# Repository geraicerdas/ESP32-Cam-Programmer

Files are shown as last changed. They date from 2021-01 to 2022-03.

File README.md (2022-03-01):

### Repository Content
* **/hardware** : Schematic files (.pdf) some of older version included Eagle design files (.sch and .brd)
* **/production** : gerber file for pcb manufacturing

You can purchase this product from  


# ESP32-Cam-Programmer
This is external programming for ESP32-Cam that you can simple attach it for easy upload your code to ESP32-Cam. Keep the slide switch at 3.3V so it is not harmful for your ESP32-Cam. ESP32-Cam programmer also have a breakout pins that makes it easier for you to connect the I/O pins of the ESP32-Cam to other circuits (no need breadboard). Not only for ESP32-Cam, you can use this board to program another MCU's like Arduino Pro mini that need USB to Serial Converter

The latest version have several changes :
- Added a 3V3 Voltage Regulator
- Added voltage selector switch (5V or 3.3V compatible)
- Compatible with both older or newer ESP32-Cam
- changes PCB shape and color

<p float="left">
 

 
</p>

If you want to make your self, just download the gerber file in production folder. Send it to your fav pcb manufacturer. And dont forget to get the Bill of materials :
|Qty | Part Name | Parts | MPN |
| --- |:---|:---| -----:|
| 2 | Female Header 8P 2.54mm pitch | J5 | X6511FV-08-C85D32 |
| 2 | Male Header 8P 2.54mm pitch | J2, J3 | X4611WRS-08I-C40D28 |
| 1 | USB type C Connector 16P | J4 | U262-161N-4BVC11 |
| 1 | CH340G/CH340C | U1 | CH340G |
| 1 | SMD Resonator 12MHz CSTCE | X1 | CSTCE12M0G15C99-R0 |
| 1 | AP2112K-3.3TRG1 | U2 | AP2112K-3.3TRG1 |
| 1 | Chip Resistor 0 0805 | R10, R11 | 0805W8F0000T5E |
| 3 | Chip Resistor 1K 0603 | R4, R6, R7 | 0603WAF1001T5E |
| 3 | Chip Resistor 10K 0603 | R1, R2, R3 | 0603WAF1002T5E |
| 2 | Chip Resistor 4K7 0603 | R8, R9 | 0603WAF4701T5E |
| 5 | Chip Capacitor 100nF 0603 | C3, C5, C6, C8, C21 | CL10B104KB8NNNC |
| 3 | Chip Capacitor 10uF 0603 | C2, C4, C7 | CL10A106KP8NNNC |
| 1 | N-Channel MOSFET AO3400 | Q1 | AO3400 |
| 2 | Transistor S8050 | Q2, Q3 | S8050 |
| 2 | Slide Switch AYZ0202W | SW | SS-3390S-L2 |
| 2 | Push Button YD3414 | S1, S2 | TS-1186U-B-A |
| 2 | SMD LED 0805 Red | RX, TX | 17-21/R6C-AQ2R2B/3T |
| 1 | SMD LED 0805 Green | PWR | 17-21/GHC-YR1S2/3T |
| 1 | Schottky Diode 1N5819HW | D1 | 1N5819WS |

Below is the first version of ESP32-Cam Programmer. We keep this for your references.

<p float="left">
 
 

</p>

## License
*We invests time and resources providing this open-source hardware, please support us by purchasing our products.*

*Designed by **[Insan Sains](https://www.youtube.com/insansains)** for **[Gerai Cerdas](https://geraicerdas.com)**, with contributions from the open source community. Creative Commons Attribution/Share-Alike, all text above must be included in any redistribution. See license.txt for additional information.*

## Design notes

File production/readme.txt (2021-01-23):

Here is the gerber files you can send to your favorite pcb manufacturer

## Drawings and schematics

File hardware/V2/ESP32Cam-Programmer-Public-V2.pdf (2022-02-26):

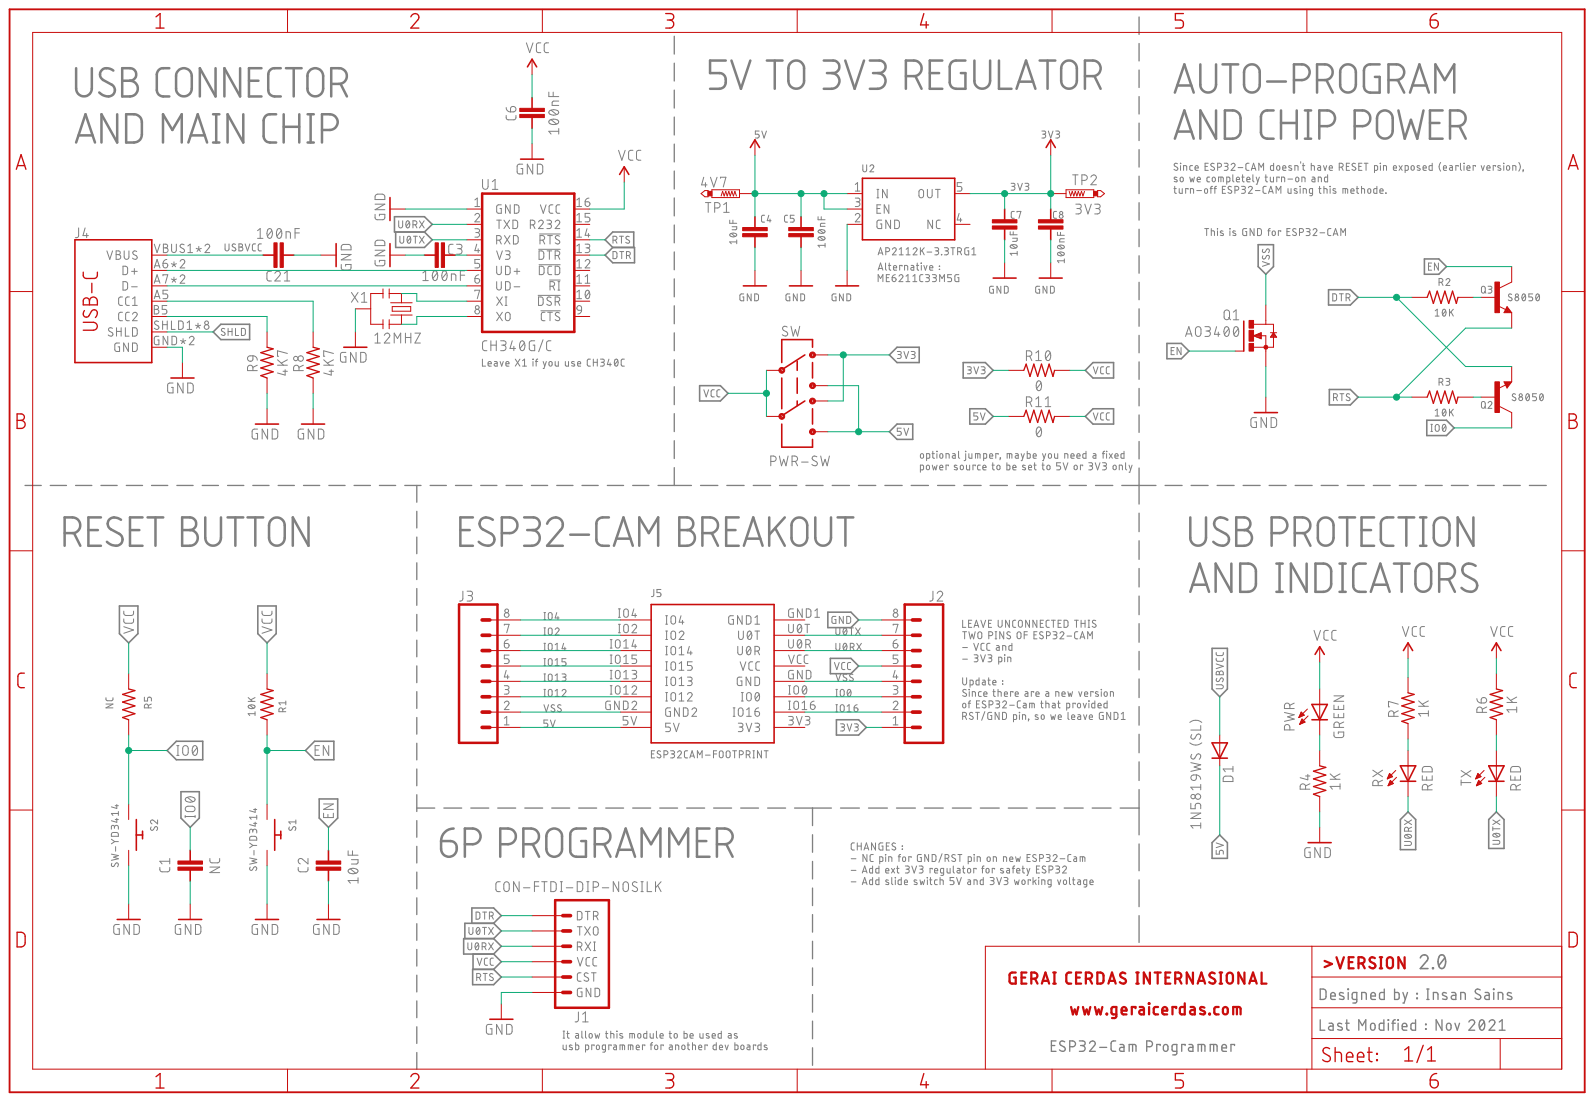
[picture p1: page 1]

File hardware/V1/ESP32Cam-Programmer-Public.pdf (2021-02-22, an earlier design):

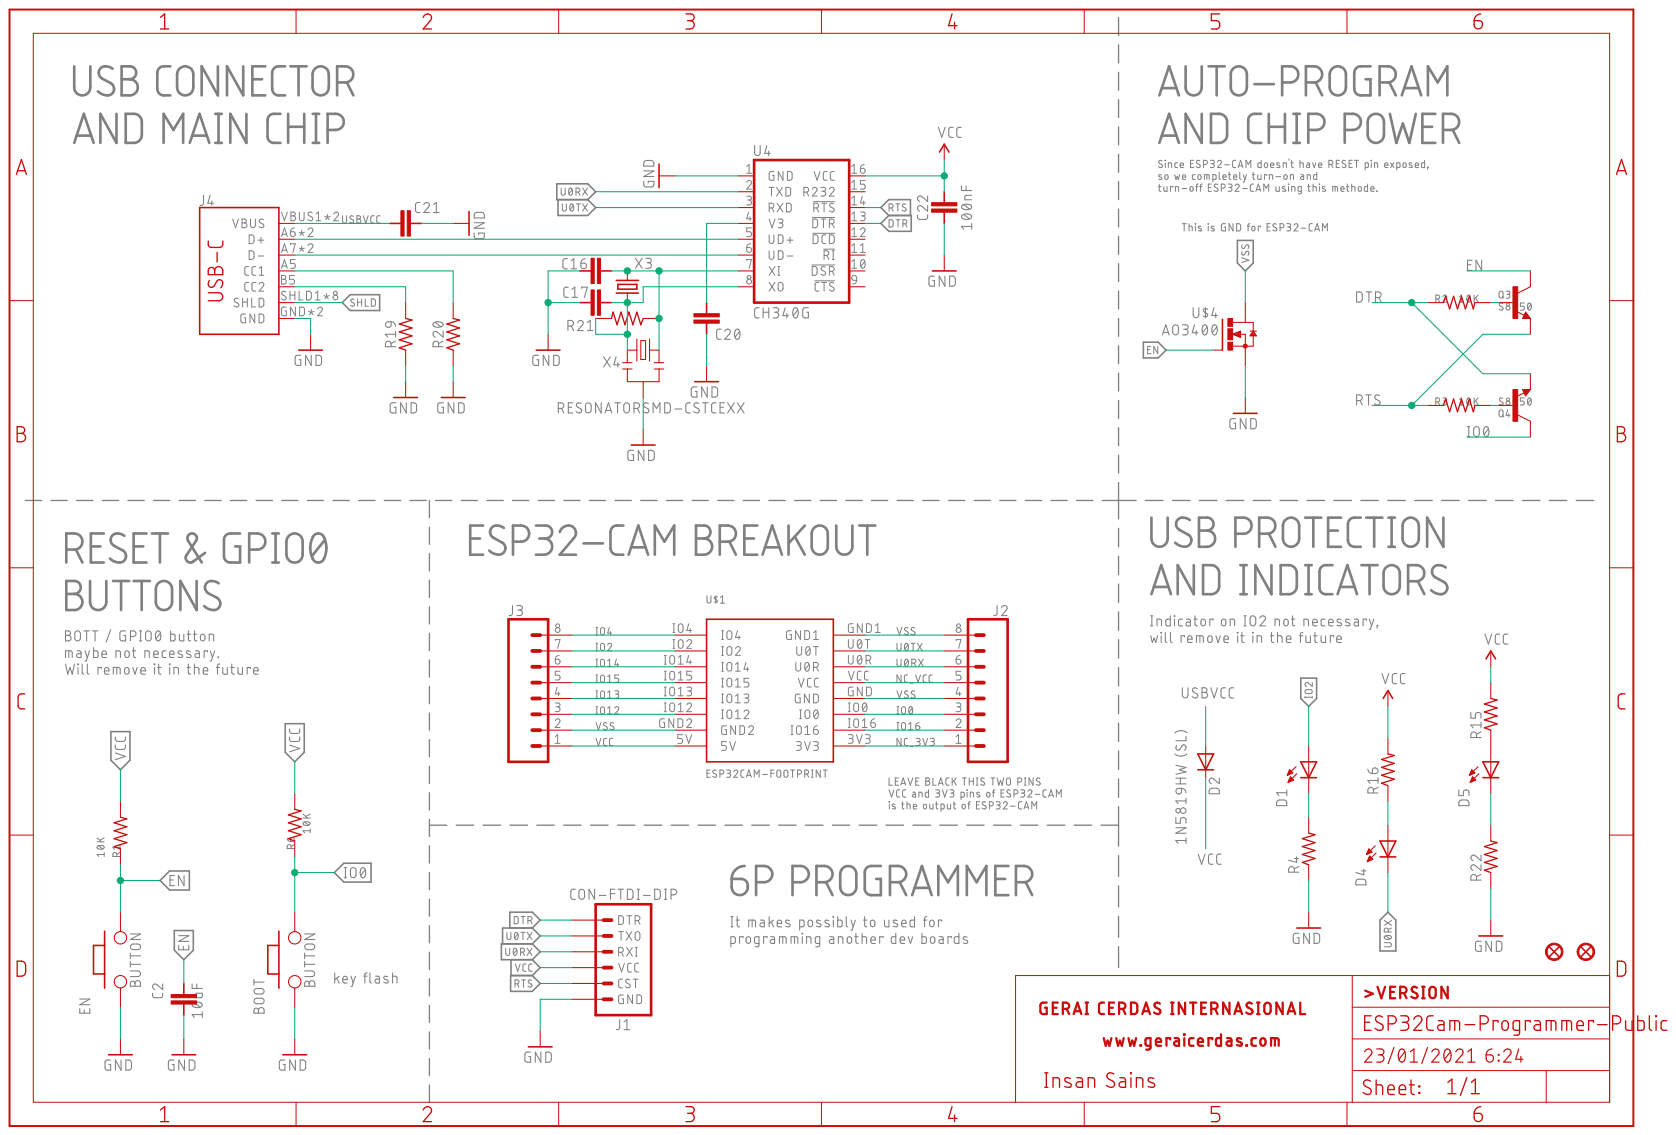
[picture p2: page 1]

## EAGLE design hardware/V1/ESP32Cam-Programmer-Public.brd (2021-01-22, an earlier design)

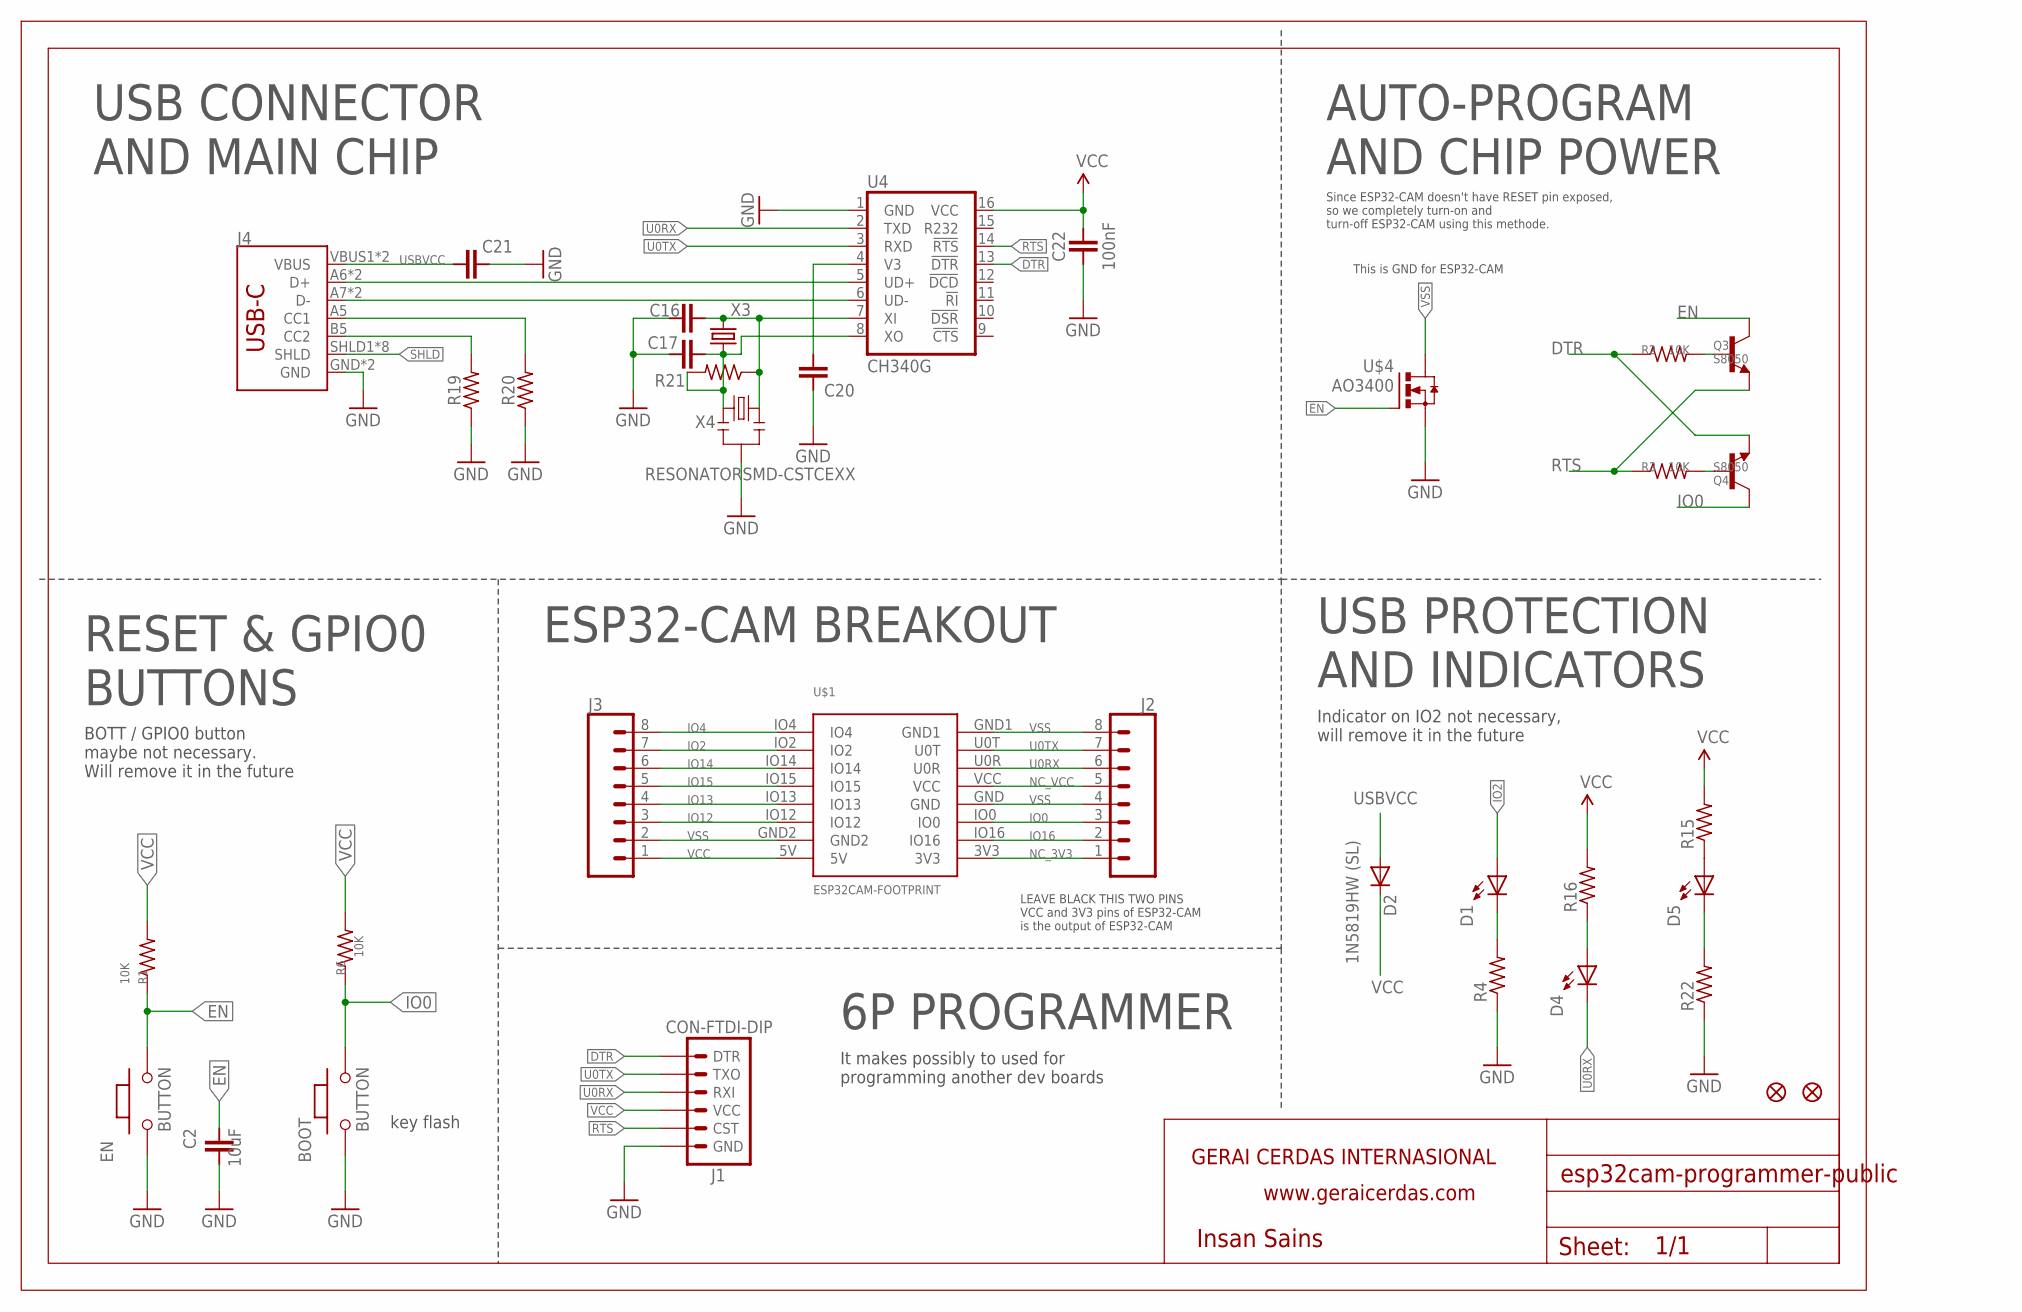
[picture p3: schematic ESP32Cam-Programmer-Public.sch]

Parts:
BOOT: BUTTON; 157SW
C2: 10uF; C0603
C16, C17: 10pF; C0603
C20: 10nF; C0603
C21, C22: 100nF; C0603
D1, D5: Yellow; LED0805
D2: 1N5819HW (SL); SOD-323
D4: GREEN; LED0805
EN: BUTTON; 157SW
J1: CON-FTDI-DIP; CON-FTDI
J2, J3: CONN_08"; 1X08
J4: USB_C16PIN; USB-C-16P
JP8, JP9: FIDUCIAL1X2; FIDUCIAL-1X2
Q3, Q4: S8050; SOT-23
R1, R2, R3, R6: 10K; R0603
R4, R22: 1K; R0603
R15, R16: 330; R0603
R19, R20: 5.1k; R0603
R21: RESISTOR-SMD0603; R0603
U4: CH340G; SO016
U$1: ESP32CAM-FOOTPRINT; ESP32CAM
U$4: AO3400; SOT-23
U$13: FRAME; A4-HOR
X3: XTAL-SMD; SMD-CRYSTAL
X4: RESONATORSMD-CSTCEXX; CSTCE*

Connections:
CC3: J4.A5 (CC1), R20.2
CC4: J4.B5 (CC2), R19.2
D+2: J4.A6 (D+), J4.B6 (D+), U4.5 (UD+)
D-2: J4.A7 (D-), J4.B7 (D-), U4.6 (UD-)
DTR: J1.DTR, Q4.2 (E), R2.1, U4.13 (!DTR)
EN: C2.2, EN.2, Q3.3 (C), R1.1, U$4.1 (G)
GND: BOOT.1, C2.1, C16.1, C17.1, C20.2, C21.2, C22.1, EN.1, J1.GND, J4.GND, J4.GND2 (GND), R4.1, R19.1, R20.1, R22.1, U4.1 (GND), U$4.2 (S), X4.2
IO0: BOOT.2, J2.3, Q4.3 (C), R6.1, U$1.IO0
IO2: D1.A, J3.7, U$1.IO2
IO4: J3.8, U$1.IO4
IO12: J3.3, U$1.IO12
IO13: J3.4, U$1.IO13
IO14: J3.6, U$1.IO14
IO15: J3.5, U$1.IO15
IO16: J2.2, U$1.IO16
unnamed: D1.C, R4.2
unnamed: Q3.1 (B), R2.2
unnamed: Q4.1 (B), R3.2
unnamed: D4.A, R16.1
unnamed: D5.A, R15.1
unnamed: C17.2, R21.2, U4.8 (XO), X3.1, X4.1
unnamed: C16.2, R21.1, U4.7 (XI), X3.2, X4.3
unnamed: D5.C, R22.2
NC_3V3: J2.1, U$1.3V3
NC_VCC: J2.5, U$1.VCC
RTS: J1.CTS (CST), Q3.2 (E), R3.1, U4.14 (!RTS)
SHLD: J4.SHLD1 (SHLD), J4.SHLD2 (SHLD), J4.SHLD3 (SHLD), J4.SHLD4 (SHLD), J4.SHLD5 (SHLD), J4.SHLD6 (SHLD), J4.SHLD7 (SHLD), J4.SHLD8 (SHLD)
U0RX: D4.C, J1.RXI, J2.6, U4.2 (TXD), U$1.U0R
U0TX: J1.TX0 (TXO), J2.7, U4.3 (RXD), U$1.U0T
USBVCC: C21.1, D2.A, J4.VBUS1 (VBUS), J4.VBUS2 (VBUS)
V1: C20.1, U4.4 (V3)
VCC: C22.2, D2.C, J1.VCC, J3.1, R1.2, R6.2, R15.2, R16.2, U4.16 (VCC), U$1.5V
VSS: J2.4, J2.8, J3.2, U$1.GND, U$1.GND1, U$1.GND2, U$4.3 (D)

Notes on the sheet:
Insan Sains
key flash
BOTT / GPIO0 button maybe not necessary. Will remove it in the future
This is GND for ESP32-CAM
LEAVE BLACK THIS TWO PINS VCC and 3V3 pins of ESP32-CAM is the output of ESP32-CAM
USB CONNECTOR AND MAIN CHIP
AUTO-PROGRAM AND CHIP POWER
USB PROTECTION AND INDICATORS
6P PROGRAMMER
ESP32-CAM BREAKOUT
RESET & GPIO0 BUTTONS
Indicator on IO2 not necessary, will remove it in the future
It makes possibly to used for programming another dev boards
Since ESP32-CAM doesn't have RESET pin exposed, so we completely turn-on and turn-off ESP32-CAM using this methode.

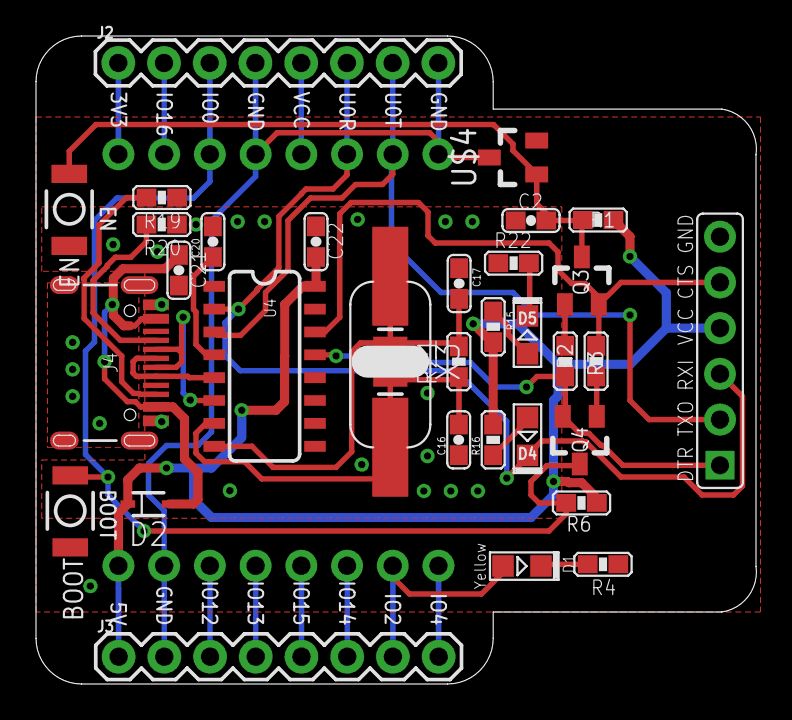
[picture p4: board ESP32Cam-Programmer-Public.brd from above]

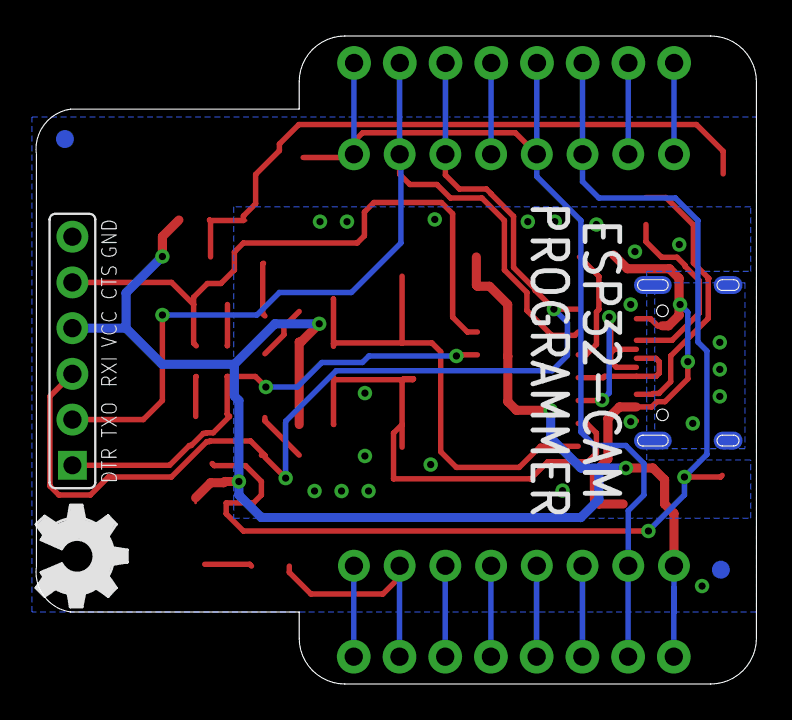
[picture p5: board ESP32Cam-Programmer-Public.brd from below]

Board: 2 copper layers, 40.0 x 36.0 mm, 38 parts (4 on the bottom side), 33 nets.

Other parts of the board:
U$2: OSHW_FILLX200_NOTEXT

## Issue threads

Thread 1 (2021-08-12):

U0R at 5V?

liudr, 2021-08-12:
@geraicerdas thanks for sharing your design! I was reviewing it and noticed that you supplied 5V to CH340, which according to the spec sheet causes it to use 5V logic level. Won't this expose ESP32's U0R pin to 5V? I've looked at my esp32-cam programming board I bought on amazon.com and it comes with a 3.3V regulator and that powers CH340 instead of 5V from USB. That board has issues with programming the esp though. Thanks.

geraicerdas, 2021-08-12:
The correct way to connect ESP32 is using 3V3 lines. It will be saver and won't damage anything. However, many of makers reported that they were able to upload code into esp32-cam module and more stable after using 5V lines. That's why in this schematic we supplied CH340G with 5V instead of 3V3.

liudr, 2021-08-12:
Thanks @geraicerdas ! Could be other issues than the voltage level. I made my own programmers for my custom ESP32-WROVER boards and have only used 3.3V logic to program it. I thought about adding a resistor voltage divider on your board but it's pretty full. I'm thinking, why not using the 3.3V pin from the esp32-cam board to power your CH340? That pin is powered by a decent 1117-3.3 regulator on the esp32-cam board and CH340 doesn't consume much. But then I thought, wait a minute. If you are toggling the GND on the esp32-cam board as a way to mimic RESET, it would cause the 1117-3.3 to lose power and then CH340 to lose power and you get a USB disconnect. It's like a chicken-egg problem. Probably best just to add some resistors somewhere.

An alternative is to use FT321X. It's more expensive but comes with an integrated 3.3V regulator to run 3.3V logic even when supplied with 5V. You probably already know that. It's indeed a few times more expensive than CH340.

geraicerdas, 2021-08-12:
I tried to keep the cost as low as possible. I just thinking another way to solve the voltage level by using 3.3V zener at U0R. What do you think?

liudr, 2021-08-12:
Yeah, if you can find a spot to fit on your board ;)

Maybe moving your transistor further to the right, near the single row of headers?

I'm using a old version or EAGLE. I would otherwise be happy to do this.

If you're interest, you could sell on tindie.com. There is a similar design someone is selling but it has no schematics and I can only infer from bits and pieces of their schematic parts shown in a video that they don't have level shifting but do have a regulator.

https://www.tindie.com/products/bitluni/cam-prog/

liudr, 2021-08-12:
BTW, if you sell them to USA, I might be able to buy a few for a project. The currently available programming board on amazon.com isn't working. They use a couple of diodes and don't actually have a working reset mechanism. I made out most of the traces of the power supply (those parts make sense) but was a bit confused how their reset button would ever work, not like there's a low-side transistor switch like yours. Here is an example on amazon. It's all over the place yet it's not really working:

https://www.amazon.com/Frienda-ESP32-CAM-ESP32-CAM-MB-Compatible-Raspberry/dp/B092ZXT1XG/

geraicerdas, 2021-08-12:
Btw, last month I faced an issue with ESP32 cam that came with programmer as link you provided. It seems a little bit different with some older ones I had before. There are an additional resistor closest to GND/R pin. It makes cannot programmed with this ESP32-Cam Programmer. But it solved by removing the additional resistor. Please check this video : https://youtu.be/RgoVah8pPh4

For your concern about voltage level, I will try a new design by adding zener or maybe bidirectional logic level converter between CH340 and the serial lines ESP32-cam. Will let you know the results.

Also thanks for remind me about tindie. I will follow up it soon with current version.

liudr, 2021-08-13:
This is just great stuff! I left a detailed comment on your video. Found the why! GND/R was the ESP32 reset pin! Someone heard the complaints!

geraicerdas, 2021-08-13:
Thank you for your details analysis. Hahaha.. finally found the why. Besides adding voltage level, I'll trying to add compatibility for both esp32-cam design in the next version. Please let me know, when you have any ideas.

liudr, 2021-08-13:
What about disconnecting that top-right GND/R pin from the rest of your ground net so that the GND/R pin is just left alone? This way your low-side power toggle will still reset the board by power-cycling it but won't hold the reset pin low. Like I said in the youtube comment, you'll have to put that tiny shunt resistor back on the board to try.

As for now, you can use a pair of pliers to remove the plastic of the top female header, then use a flush cutter to cut out the fork-shaped pin and then put the plastic female header back on. Indeed if you have more boards of your current revision, you can just use pliers to pull out that female pin before soldering it or tell your buyer about this when they assemble their board. This way your existing programmer will not be connected to that GND/R pin. I checked on my older esp32-cam board. All its GND pins are connected together (as I expected). So not having one of the three GND pins is fine. Let me know if this works. If it does, you can easily modify your future board to be compatible with both old and new esp32-cam.

Hey, now to think about it, why that tindie.com seller from Germany has his boards out of stock, maybe that's when the revision changed and his board stopped working?! Just a wild guess. I found his board and was gonna buy his but it was out of stock and I later found your git repo from a project team member searching for reliable cam programmer boards. It's all a pretty rewarding adventure. We solved a problem together even though physically live on the opposite sides of the globe. I'm in midwest USA BTW.

Closed 2021-08-13.

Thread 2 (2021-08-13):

Part number for the USB-C connector and crystal

liudr, 2021-08-13:
Hi,
Thanks for the design always! Is it possible to share the part number for the USB-C connector and the crystal?
I've run into issues with mismatched crystals in the past so I would appreciate a part number for that. Thanks again!

geraicerdas, 2021-08-14:
I use U262-161N-4BVC11 for USB type C connector. It has 16 pin SMD
And for 12Mhz Crystal : 72012000RW1

liudr, 2021-08-15:
Great! Thanks much!

Closed 2021-09-26.

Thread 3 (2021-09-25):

automatic reset by software not working (hard resetting via rts pin)

linsThankachan, 2021-09-25:
hello,
i'm using an esp32 cam and i have used your circuit to realise automatic code upload. Firstly thank u for that . there is a problem in my final board the automatic reset that is given by arduino software (hardresetting via rts pin) is not working.
can you tell me why?
[Schematic_esp32_cam_board_2021-09-25.pdf](https://github.com/geraicerdas/ESP32-Cam-Programmer/files/7230161/Schematic_esp32_cam_board_2021-09-25.pdf)

geraicerdas, 2021-09-26:
Hi, Have you tried to assemble and test the ESP32 and the auto-program circuit only?

linsThankachan, 2021-09-28:
now it is working perfectly.
connecting anything to the straping pins will result in reset not working. I have another doubt why is that c2 capacitor which is connected to EN used. is it used for debounce of the EN switch? and do we need the 10K pullup resistor(R6) because GPIO0 is already pulled up internally when GND is not applied to it.

geraicerdas, 2021-09-28:
Thank for the updates. C2 with the specific value from 1-10nF is the important thing. It not used for debouncing EN button only, but it allow EN to be slow to rise while IO0 falls low. This state will giving the opportunity of correct timing (rise-fall) for ESP32 so it can enter the programming mode. And yes, for the R6 connected to BOOT button as mentioned in the legend of schematic, that parts might be not necessary as your thought.

linsThankachan, 2021-09-28:
so C2 is in nF range not in uF. typed wrongly?
In the schematic it is 10uF.
i have done without capacitor(10uF) also and it is working.

geraicerdas, 2021-09-28:
Sorry. 1-10uF. I've tried a large numbers of ESP32, without this cap, I only success with a few board. This cap help all boards can be done without any issues.

linsThankachan, 2021-09-28:
OK thank you for your help.
Closing the issue

Closed 2021-09-28.

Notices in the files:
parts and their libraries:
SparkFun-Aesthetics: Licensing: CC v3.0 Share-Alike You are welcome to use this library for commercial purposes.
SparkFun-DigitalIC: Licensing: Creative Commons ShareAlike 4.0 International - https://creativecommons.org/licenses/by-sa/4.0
